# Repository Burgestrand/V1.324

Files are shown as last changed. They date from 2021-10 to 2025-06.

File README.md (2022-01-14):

# V1.324

> See [vorondesign.com/Voron Trident](https://vorondesign.com/voron_trident) for information about what all this is.

https://user-images.githubusercontent.com/99166/149587983-16803544-f759-469c-964e-828752e986d1.mp4

You want to build something like this? You should [join the discord](https://discord.com/invite/voron). You can find lots of
good help in there. I'm probably there too!

## Repository Contents

- [./hardware/](./hardware) contains information about the build, the individual parts, and how I sourced everything.
- [./software/](./software) contains information about the operating system and klipper config.
- [./gallery/](./gallery) contains a series of images and videos.

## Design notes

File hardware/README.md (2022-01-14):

# The Hardware

- **Hotend:** [Phaetus Dragon HF x Voron Edition](https://www.phaetus.com/phaetus-x-voron-hotend-hf/)
- **Control Board:** [BTT Octopus V1.1](https://www.biqu.equipment/products/bigtreetech-octopus-v1-1)
- **Bed Heater:** [400W Keenovo Bed Heater](https://keenovo.store/collections/standard-keenovo-silicone-heaters/products/keenovo-square-silicone-heater-3d-printer-build-plate-heatbed-heating-pad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).
- **Motors:** [OMC StepperOnline](https://www.omc-stepperonline.com/).
- **Frame:** [Misumi](#misumi-extrusions).
- **PSU:** [Mean Well RSP-200-24](https://www.meanwell-web.com/en-gb/ac-dc-single-output-enclosed-power-supply-output-rsp--200--24).
- **Bed:** MIC6 Cast Aluminum bed.

## Everything is stock, until it isn't...

- [eddies LED bar clips](https://github.com/VoronDesign/VoronUsers/tree/master/printer_mods/eddie/LED_Bar_Clip) to mount 5050 LEDs to the inside of the top extrusions.
- [nevermore micro v5 duo](https://github.com/nevermore3d/Nevermore_Micro) for cleaning the chamber air.
- [VEFACH](https://github.com/VoronDesign/VoronUsers/tree/master/printer_mods/KevinAkaSam/VEFACH) for cleaning the exhaust air.
- [decontaminator and nozzle scrubber](https://github.com/VoronDesign/VoronUsers/tree/master/printer_mods/edwardyeeks/Decontaminator_Purge_Bucket_&_Nozzle_Scrubber) for cleaning the nozzle when calibrating in before a print.
- 3x5 angle wago mount (STL?) for mains wiring.
- 6x2 wago mount for bed wiring (STL?).
- right angle decontaminator bucket mount (STL?).

## Sourcing Information

All parts were sourced individually and not from a kit. Notable sources are:

- [maskindelen.se](maskindelen.se) for nearly all of my fasteners.
- [digikey.se](digikey.se) for genuine electronics (omron switches, SSR, molex kit).
- [conrad.se](conrad.se) for the [PSU](https://www.conrad.se/p/mean-well-rsp-200-24-acdc-naetdel-sluten-84-a-201-w-24-vdc-1293010), electrical outlets, and some random bits and bobs.
- [tme.eu](tme.eu) for wires. I use [LAPP ÖLFLEX HEAT 260 SC](https://se.lappgroup.com/produkter/webshop/kablar/temperaturbestaendig-kabel/ptfe-kabel-190c-till-260c/oelflex-heat-260-sc.html) PTFE wiring in my drag chains.
- [vonwange.com](vonwange.com) for hotend, thermistors, heater.
- [kris3d.de](https://www.kris3d.de/) for the aluminium bed, bowden tube, dupont connnectors.
- [mouser.se](mouser.se) for electronics unavailable at digikey.
- [oljemagasinet](oljemagasinet.se) for the [EP2 grease](https://www.oljemagasinet.se/index.php?route=product/product&product_id=721&filter_name=mobilux%20ep2).
- [print it forward](https://pif.voron.dev/) for the printed parts.
- [aliexpress](https://www.aliexpress.com/) for everything where quality and delivery speed aren't important.

### Misumi Extrusions

I ordered my aluminium extrusions from [Misumi](https://uk.misumi-ec.com).

Misumi does not sell to consumers. I had the luck of meeting a new friend in Discord from Germany who ordered frames for me and shipped them to Sweden. Per their recommendation I ordered the extrusions untapped and drilled, and saved myself half the cost. In addition I got to learn how to drill and tap aluminium. Fun!

## Panels

See [panels/](./panels) for details on the pink acrylic mirrors.

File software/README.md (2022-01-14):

# Software

- **Board:** [Raspberry Pi 4B](https://www.raspberrypi.com/products/raspberry-pi-4-model-b/)
- **OS:** [Mainsail](https://docs.mainsail.xyz/)

## Klipper

See [./klipper_config/](./klipper_config) for my current configuration.

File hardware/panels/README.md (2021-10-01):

# Panels

All panels where ordered in one go from [interglas.se](https://interglas.se/). They
were unable to accommodate measurements finer than whole millimeters, so I needed to adjust the DXFs
from the official repository.

This is where the adjusted drawings live. The original DXFs are from [VoronDesign/Voron-Trident](https://github.com/VoronDesign/Voron-Trident).

Interglas also wanted PDF drawings with annotated measurements. I might have gone a bit overboard.

## The Order

This is the order as I sent it to interglas.

- Three sheets of laser-cut acrylic.
  1. [Bottom](./Bottom.pdf) (369x369, [3PMMACl101][]) — 210 SEK.
  2. [Deck](./Deck.pdf) (369x369, [3PMMA1750PINK][]) — 333 SEK.
  3. [Rear](./Rear.pdf) (383x473, [3PMMA1750PINK][]) — 333 SEK.
- Five sheets of cut-to-measure acrylic.
  1. 2 x [4CE03CUT][], 191x473 (two doors) — 256 SEK.
  2. 2 x [4CE03CUT][], 383x473 (two sides) — 336 SEK.
  3. 1 x [4CE03CUT][], 383x383 (one top) — 136 SEK.

Shipping was 179 SEK.

Total order including 25% VAT was ~1800 SEK.

[3PMMACl101]: https://interglas.se/shop/akryl-klar-3-500p.html
[3PMMA1750PINK]: https://interglas.se/shop/3-mm-spegel-4159p.html
[4CE03CUT]: https://interglas.se/shop/polykarbonat-klar-3-749p.html

## Notes

* Some of the original DXFs had odd measurements such as 139.9 and 140.1 — this is probably an error.
* I managed to adjust the measurements of all panels in-place except for the bottom, which I had to redo entirely. I was in a hurry so the bottom panel is the one with the widest margins.

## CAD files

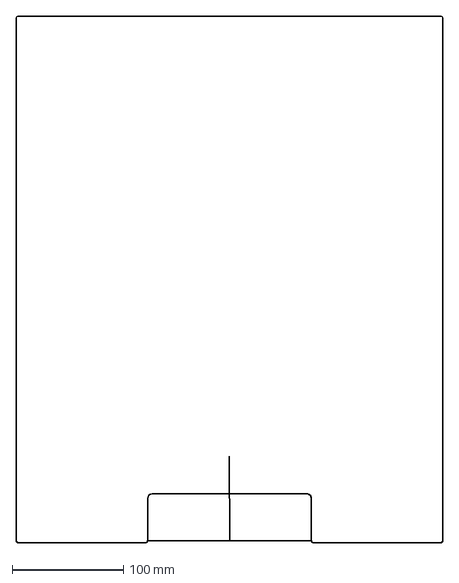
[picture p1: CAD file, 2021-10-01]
hardware/panels/Rear.dxf
383.0 x 473.0 mm

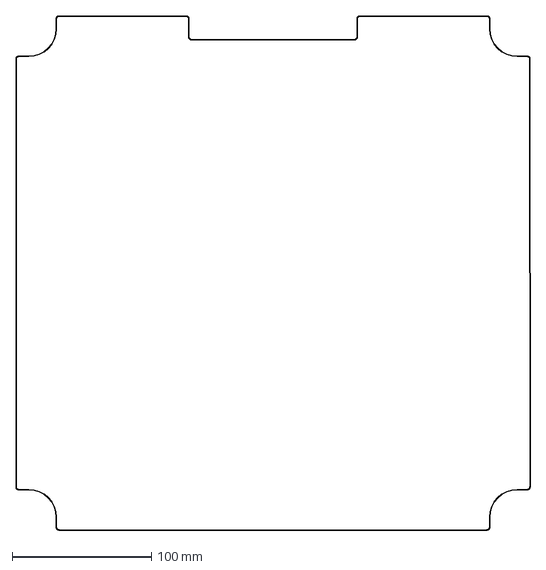
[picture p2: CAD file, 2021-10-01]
hardware/panels/Bottom.dxf
369.0 x 369.0 mm

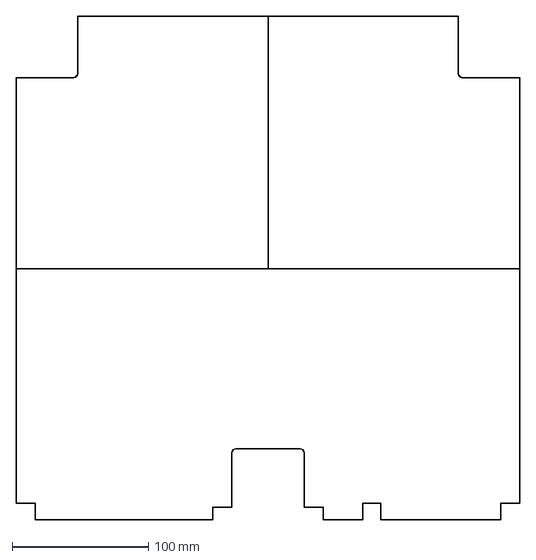
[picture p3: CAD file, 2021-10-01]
hardware/panels/Deck.dxf
369.0 x 369.0 mm

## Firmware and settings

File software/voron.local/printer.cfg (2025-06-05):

[include mainsail.cfg]
[include btt_octopus_pin_aliases.cfg]
[include btt_sb2209_pin_aliases.cfg]

[include printer/macros.cfg]
[include printer/steppers.cfg]
[include printer/bed.cfg]
[include printer/input_shaper.cfg]
[include printer/nevermore.cfg]

[include printer/display.cfg]
[include printer/toolhead.cfg]

[mcu]
serial: /dev/serial/by-id/usb-Klipper_stm32f446xx_15003500165053424E363620-if00

[printer]
kinematics: corexy
max_velocity: 600
max_accel: 20000 # 10900 (mzv)
minimum_cruise_ratio: 0.5
max_z_velocity: 30
max_z_accel: 350
square_corner_velocity: 5.0

[exclude_object]

[extruder]
nozzle_diameter: 0.6
filament_diameter: 1.75 # due to 1.8 CHT

[idle_timeout]
timeout: 1800
gcode:
  TURN_OFF_HEATERS
  M84 ; Turn off motors
  M117 Idling out!

# https://docs.mainsail.xyz/quicktips/additional-sensors
[temperature_sensor raspberry_pi]
sensor_type: temperature_host
min_temp: 10
max_temp: 80

# https://docs.mainsail.xyz/quicktips/additional-sensors
[temperature_sensor mcu_temp]
sensor_type: temperature_mcu
min_temp: 10
max_temp: 80

[static_digital_output caselight]
pins: HE1

#
# Having this config here allows Klipper to save it!
#

[stepper_z]
# (+) value = endstop is *above* Z0 (bed), (-) value = endstop *below* bed
# Increasing position_endstop brings nozzle closer to the bed
position_endstop: 0.300

[heater_bed]
#control: pid
#pid_Kp=28.815
#pid_Ki=0.679
#pid_Kd=305.801

[extruder]
control: pid
pid_Kp=36.049
pid_Ki=4.216
pid_Kd=77.054

#*# <---------------------- SAVE_CONFIG ---------------------->
#*# DO NOT EDIT THIS BLOCK OR BELOW. The contents are auto-generated.
#*#
#*# [stepper_z]
#*# position_endstop = 0.192
#*#
#*# [heater_bed]
#*# control = pid
#*# pid_kp = 42.639
#*# pid_ki = 1.744
#*# pid_kd = 260.629
#*#

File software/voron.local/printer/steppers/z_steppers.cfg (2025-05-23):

# Left Front
[stepper_z]
enable_pin: !MOT2_EN
step_pin: MOT2_STEP
dir_pin: !MOT2_DIR

# Rotation
microsteps: 8
rotation_distance: 8 # TR8x8
full_steps_per_rotation: 200

# Endstop
endstop_pin: ESTOP0

# Z Height
position_max: 235
position_min: -2.5
homing_speed: 10.0
homing_retract_dist: 2
second_homing_speed: 5

# Driver
[tmc2209 stepper_z]
uart_pin: MOT2_CS
run_current: 0.75
interpolate: False
stealthchop_threshold: 99999999

# Rear
[stepper_z1]
enable_pin: !MOT0_EN
step_pin: MOT0_STEP
dir_pin: !MOT0_DIR

# Rotation
microsteps: 8
rotation_distance: 8 # TR8x8
full_steps_per_rotation: 200

[tmc2209 stepper_z1]
uart_pin: MOT0_CS
run_current: 0.75
interpolate: False
stealthchop_threshold: 99999999

# Right Front
[stepper_z2]
enable_pin: !MOT1_EN
step_pin: MOT1_STEP
dir_pin: !MOT1_DIR

# Rotation
microsteps: 8
rotation_distance: 8 # TR8x8
full_steps_per_rotation: 200

[tmc2209 stepper_z2]
uart_pin: MOT1_CS
run_current: 0.75
interpolate: False
stealthchop_threshold: 99999999

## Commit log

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2021-12-26 Add my current Klipper configuration
    [M600.cfg, ab_steppers.cfg, adxl345.cfg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]
2021-12-26 Adjust bed position to span (0,0) to (245,245)
    [ab_steppers.cfg, bed.cfg, klicky-probe.cfg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]
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2021-12-26 Adjust bed mesh points according to probe offset
    [bed.cfg]
2021-12-26 Adjust G32 to work with automatic Z calibration
    [G32.cfg, bed.cfg, macros.cfg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]
2021-12-26 No need to dock probe before Z calibration
    [z_calibration.cfg]
2021-12-26 Reduce notification noise from Z calibration
    [start-stop.cfg, z_calibration.cfg]
2021-12-27 Klicky sometimes fail to attach
    [klicky-probe.cfg, z_calibration.cfg]
2021-12-27 Add purge bucket and nozzle scrubber
    [clean.cfg, z_calibration.cfg]
2021-12-27 SAVE_GCODE_STATE clears the Z offset from Z calibration
    [G32.cfg, bed.cfg, start-stop.cfg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]
2021-12-29 Fix Z calibration print start routine with purge unload/load
    [calibrate.cfg, clean.cfg, macros.cfg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]
2021-12-29 Tune printer PID and Z offset
    [printer.cfg, z_calibration.cfg]
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2021-12-31 NTC 100K is deprecated
    [bed.cfg]
2021-12-31 Park over purge bucket
    [start-stop.cfg]
2021-12-31 Split out brush macro into components
    [clean.cfg]
2022-01-05 Wrong SPI software MISO/MOSI/SCLK pins!
    [display.cfg]
2022-01-05 Klipper recommends not setting `hold_current`
    See https://www.klipper3d.org/TMC_Drivers.html#prefer-to-not-specify-a-hold_current
    In short, it might make the motor move a tiny bit when the current is reduced.
    [ab_steppers.cfg, afterburner.cfg, z_steppers.cfg]
2022-01-05 Disable interpolating for better accuracy
    … and increase microsteps to reduce noise.
    See: https://www.klipper3d.org/TMC_Drivers.html#tmc-interpolate-setting-introduces-small-position-deviation
    TMC 2209 datasheet says 2, 4, 8, 16, 32, 64, 128, or 256 are fine: https://www.trinamic.com/fileadmin/assets/Products/ICs_Documents/TMC2209_Datasheet_V103.pdf
    [ab_steppers.cfg, afterburner.cfg, z_steppers.cfg]
2022-01-05 Clean up start/stop macros (better for PETG…)
    [calibrate.cfg, clean.cfg, mainsail.cfg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]
2022-01-05 Let's not change interpolation on extruder
    … not yet anyway. We would need to re-calibrate e-steps. I guess ideally we should enable it and keep a low number of e-steps since stealthchop can introduce inaccuracy?
    [ab_steppers.cfg, afterburner.cfg]
2022-01-05 Fix display pin assignment, MISO/MOSI was wrong!
    [display.cfg]
2022-01-14 Moved panels into build subdirectory
    [Bottom.dxf, Deck.dxf, Rear.dxf]
2022-01-14 move things around for fun
    [Bottom.dxf, Deck.dxf, M600.cfg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]
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2022-04-05 Move faster between purge bucket and Z endstop
    Homing speed is slow. We can move much quicker close to Z endstop to reduce chance of oozing.
    [calibrate.cfg]
2022-04-05 Move closer to cleaning brush for a deeper clean.
    [clean.cfg]
2022-04-05 Need a little more squish.
    [z_calibration.cfg]
2022-04-05 Interpolate A/B in an attempt to reduce resonance
    [ab_steppers.cfg]
2022-04-05 Stealthchop is back baby!
    [z_steppers.cfg]
2022-04-05 Avoid power cycling print fan during heat soak
    The nozzle hovers around 50C during heat soak, which made the part cooling fan turn on and off.
    [afterburner.cfg]
2022-04-05 We need >33% exhaust to keep negative pressure
    To avoid fumes leaking out the access holes
    [nevermore.cfg]
2022-04-05 This macro makes no sense to call manually
    [macros.cfg]
2022-04-05 Included in mainsail v2.1
    [macros.cfg]
2022-04-05 Make PRINT_START verify the Nozzle size
    Klipper has a nozzle size, Slicer has a nozzle size… they should be the same.
    [printer.cfg, start-stop.cfg]
2022-04-05 Manually control Nevermore to allow for delayed stop
    This keeps Nevermore running for ABS only, and stops it 10 minutes after print.
    [afterburner.cfg, nevermore.cfg, start-stop.cfg]
2022-04-05 Use a shorter retraction length at end of prints
    This pulls the filament into the cold side plus a bit of a margin, should stop pushing the bowden tube up.
    [reload.cfg]
2022-04-05 Do not do interpolation for X/Y and compensate with microsteps for audio
    [ab_steppers.cfg]
2022-04-06 Update configuration for recent upgrade
    - stealthburner
    - new wiring
    [afterburner.cfg, bed.cfg, leds.cfg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]
2022-04-06 Add macro for flow calibration
    [flow-calibration.cfg, macros.cfg]
2022-04-06 Make purge line *much more* intelligent
    … it calculates how many purge lines and feed rate automatically based on how much filament we want to extrude!
    [clean.cfg, start-stop.cfg]
2022-04-06 Thicker line width for purge line for better adhesion
    Also requires fewer lines :D
    [clean.cfg]
2022-04-06 We don't brush nozzle, there is no brush at the moment :(
    [calibrate.cfg]
2022-04-06 Wiggle during flow calibration signal "ready!"
    This means we should remove the string
    [flow-calibration.cfg]
2022-04-09 Make wiggle/home optional in flow calibration
    [flow-calibration.cfg]
2022-04-10 Be closer for flow calibration for better swirl
    Closer to bed = filament has less to travel and curls up in a ball nicer.
    [flow-calibration.cfg]
2022-04-10 Collect everything printer-related to printer/
    I keep looking inside printer/ for macros :(
    [M600.cfg, afterburner.cfg, calibrate.cfg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]
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2022-04-10 Remove old unused configuration
    There's no point in having old configuration now that I've got version control on this.
    [afterburner.cfg, display.cfg, klicky-probe.cfg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]
2022-04-11 Sprinkle SB leds status everywhere
    [calibrate.cfg, clean.cfg, klicky-probe.cfg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]
2022-04-11 Improve Z axis accuracy
    Lower number of microsteps (more accurate) and higher run current (stronger, e.g. more accurate).
    [z_steppers.cfg]
2023-03-30 First sync in a long time! New toolhead.
    [M600.cfg, ab_steppers.cfg, flow-calibration.cfg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]
2023-07-22 Sync config before update
    [stealthburner.cfg, z_calibration.cfg, z_probe.cfg]
2023-07-23 Update all dependencies and their config
    KlickyNG, new z calibration, new Klipper/mOonraker/mainsail.
    [bed.cfg, klicky-bed-mesh-calibrate.cfg, klicky-macros.cfg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]
2025-05-22 A lot has changed!
    [M600.cfg, bed.cfg, calibrate.cfg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]
2025-05-23 Adjust pins and config for new layout
    [ab_steppers.cfg, adxl345.cfg, bed.cfg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]
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2025-05-23 Mainsail is actually a symlink
    [mainsail.cfg]
2025-05-23 Update config from mac
    [ab_steppers.cfg, adxl345.cfg, bed.cfg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]
2025-05-23 Remove superfluous old voron_config
    [ab_steppers.cfg, adxl345.cfg, bed.cfg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]
2025-05-23 Update stealthburner with new toolhead config
    [M900.cfg, leds.cfg, macros.cfg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]
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2025-05-23 Wrong name!
    [printer.cfg]
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2025-05-23 Swap stepper pins
    [ab_steppers.cfg]
2025-05-23 Swap z2 and z
    [z_steppers.cfg]
2025-05-23 Reverse X/Y stepper
    [ab_steppers.cfg]
2025-06-01 Used wrong port when debugging
    [z_probe.cfg]
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
